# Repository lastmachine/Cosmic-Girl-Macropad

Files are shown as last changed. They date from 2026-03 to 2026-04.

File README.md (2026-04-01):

# Cosmic-Girl-Macropad
A personal cosmic-themed XIAO-RP2040-powered macropad for games, video editing, or anything you'd like to customize. It features 9 MX-style switches, 1 EC11 rotary encoder, and a 128x32 OLED screen.

Having 9 keys makes it perfect for media editing and streaming; those are the main usages I want to give it. Of course, this macropad would work for anything else that allows custom binds. KMK firmware written in Python, is open to modifications 

It is called "Cosmic Girl" because I really like the song of the same name created by the band "Jamiroquai," and also space aesthetics.

Made using KiCad, Fusion 360, and Visual Studio Code. For Hack Club Blueprint.

## Render & Snapshot - Fusion 360
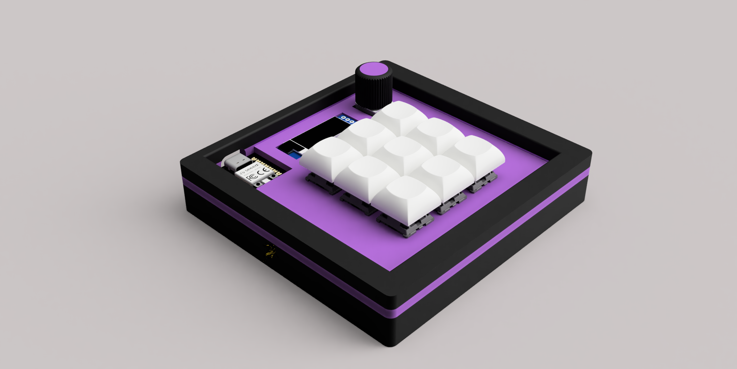
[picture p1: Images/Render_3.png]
Render

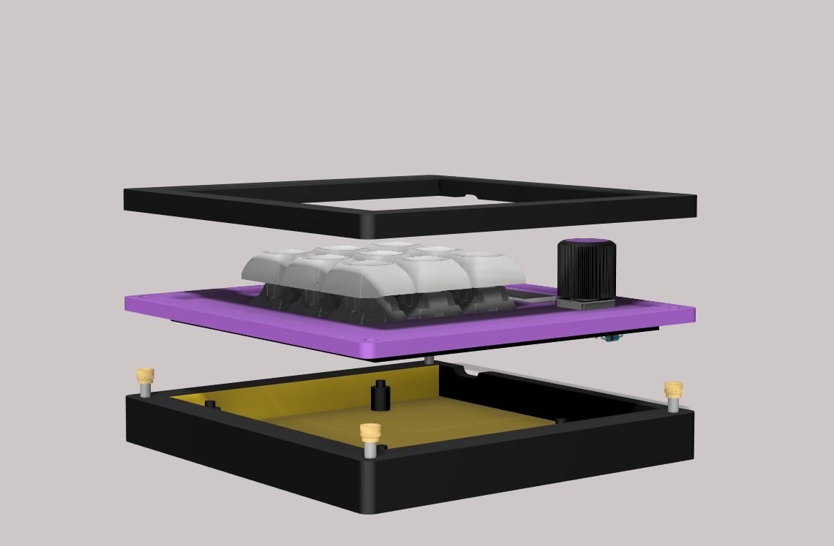
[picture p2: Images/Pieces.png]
Parts

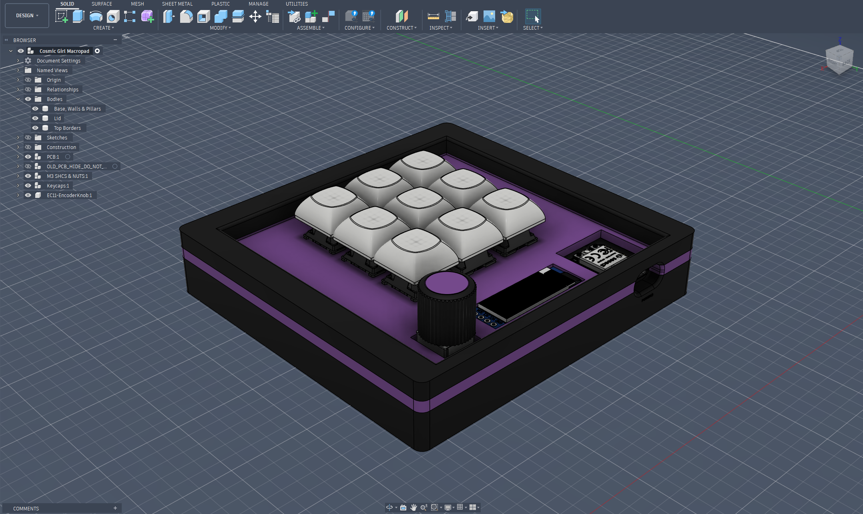
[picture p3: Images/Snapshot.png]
Snapshot

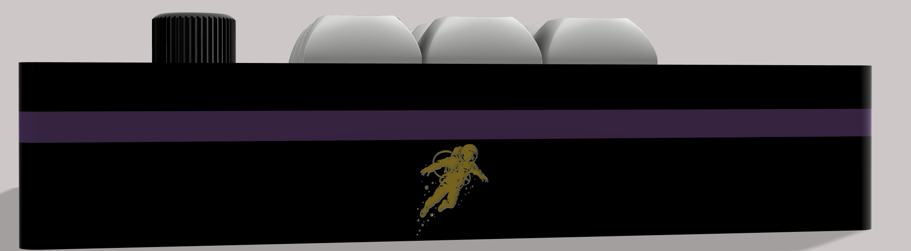
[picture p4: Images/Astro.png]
Astro


---
## PCB & Schematic - KiCad 
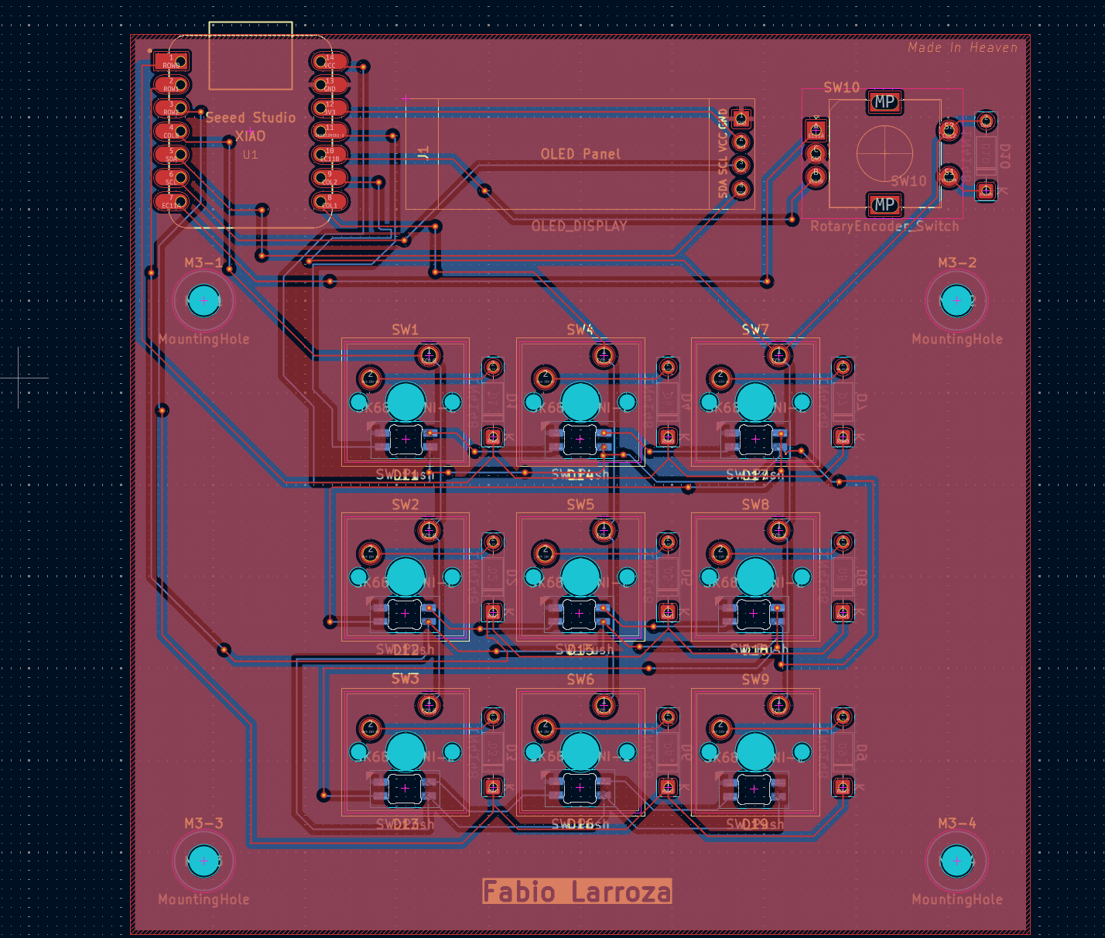
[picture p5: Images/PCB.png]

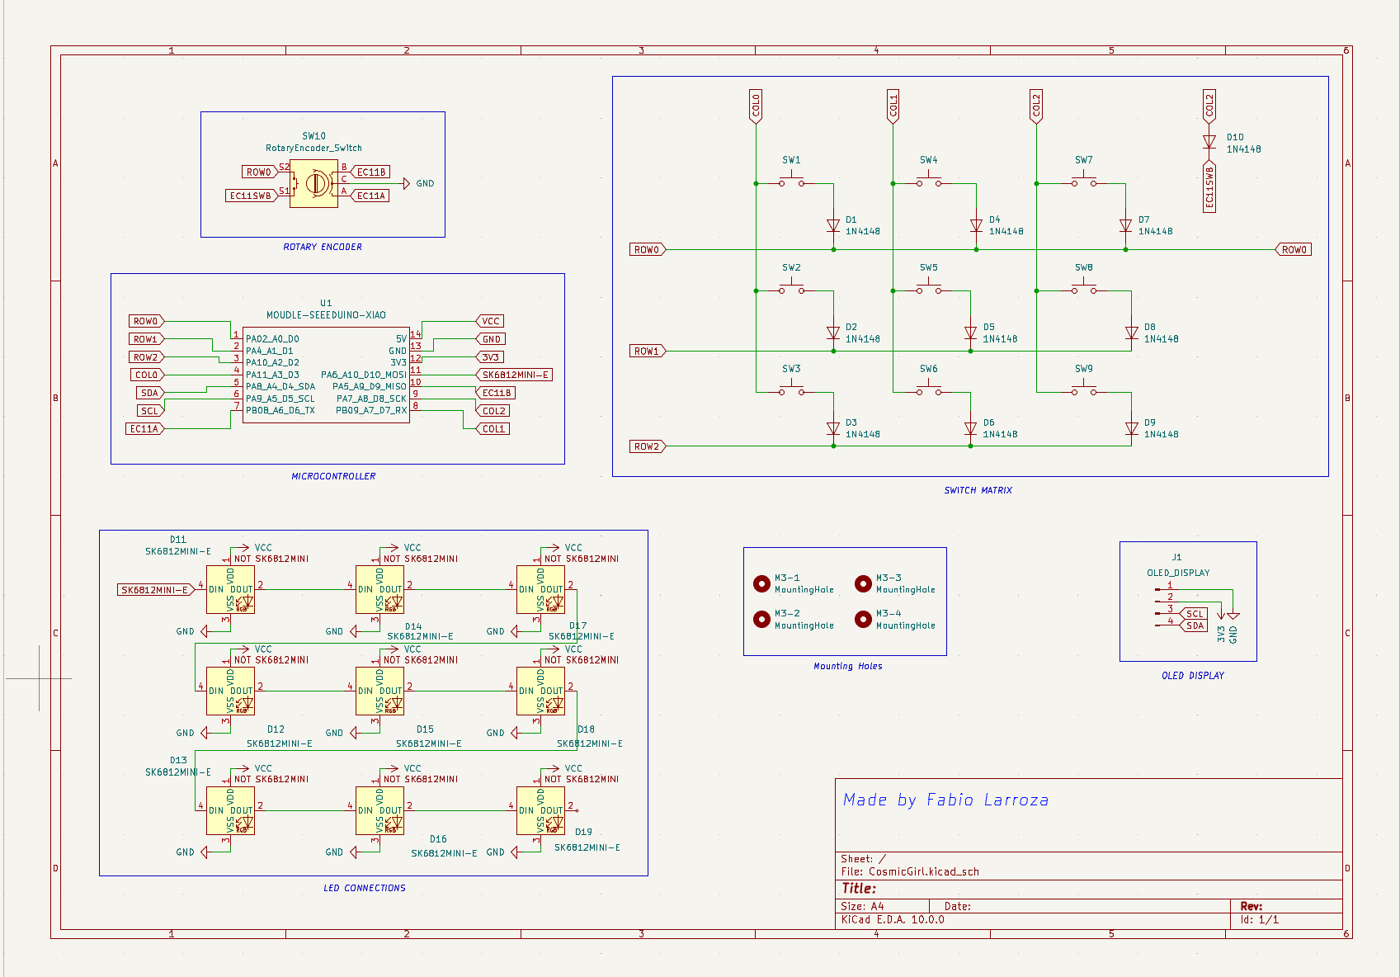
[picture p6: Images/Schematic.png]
Schematic


---
## 3D
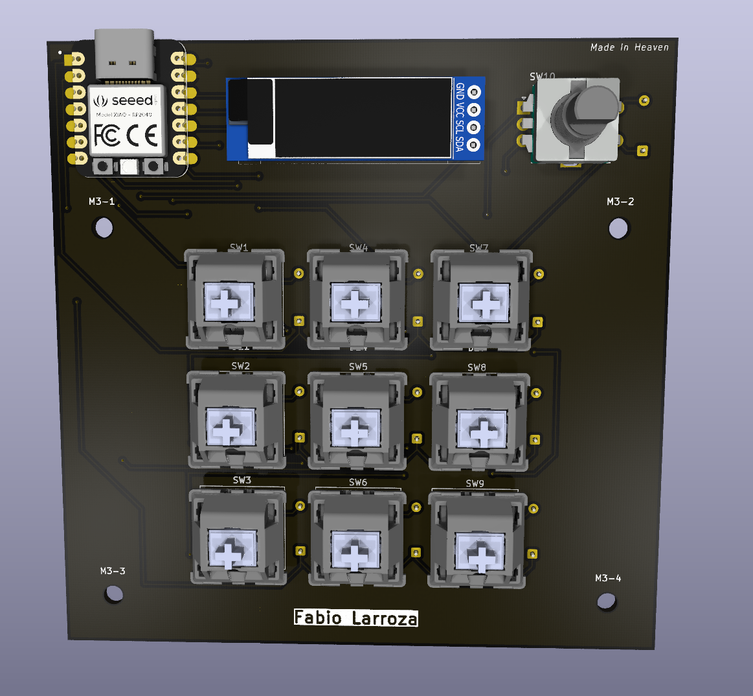
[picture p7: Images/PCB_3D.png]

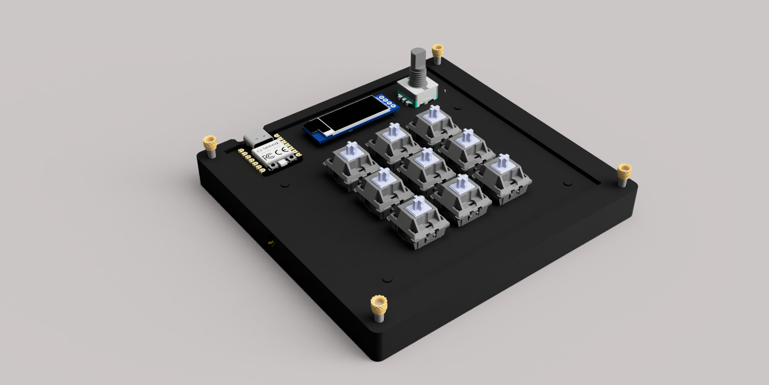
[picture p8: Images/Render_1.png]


---
## Bill of Materials

| Part | Quantity | Details |
|---|---|---|
| Seeed XIAO RP2040 | 1 | Unsoldered |
| 1N4148 Diode | 10 | Through-hole |
| MX-Style Switch | 9 | |
| EC11 Rotary Encoder | 1 | D-Shaft |
| 0.91" OLED Display | 1 | I2C, 128x32 |
| DSA Keycap (white blank) | 9 | |
| SK6812 MINI-E LED | 9 | |
| M3x16mm Screw | 4 | |
| M3x5x4mm Heatset Insert | 4 | |
| Custom PCB | 1 | 2-layer, 98x98mm|

---
## Attribution
Rotary encoder knob model adapted from [EC11 Encoder Knob](https://www.printables.com/model/1000044-ec11-encoder-knob) by Kea Workshop, licensed under GNU GPL v2.0

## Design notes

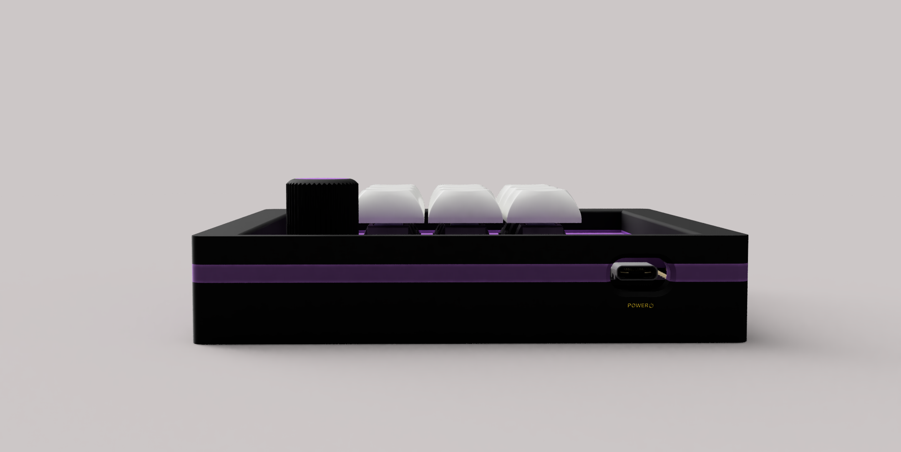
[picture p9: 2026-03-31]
Images/Render_2.png

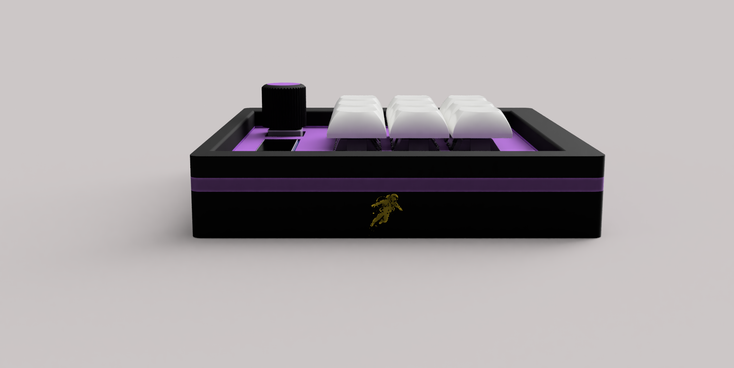
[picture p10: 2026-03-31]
Images/Render_4.png

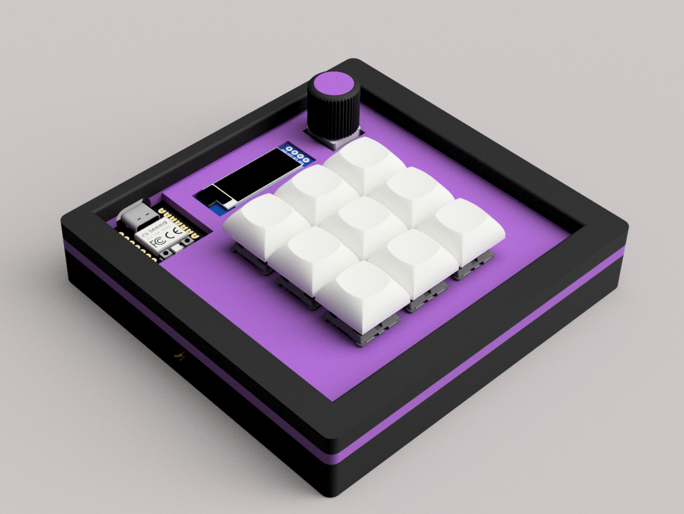
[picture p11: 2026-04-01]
Images/Closeup_model.png

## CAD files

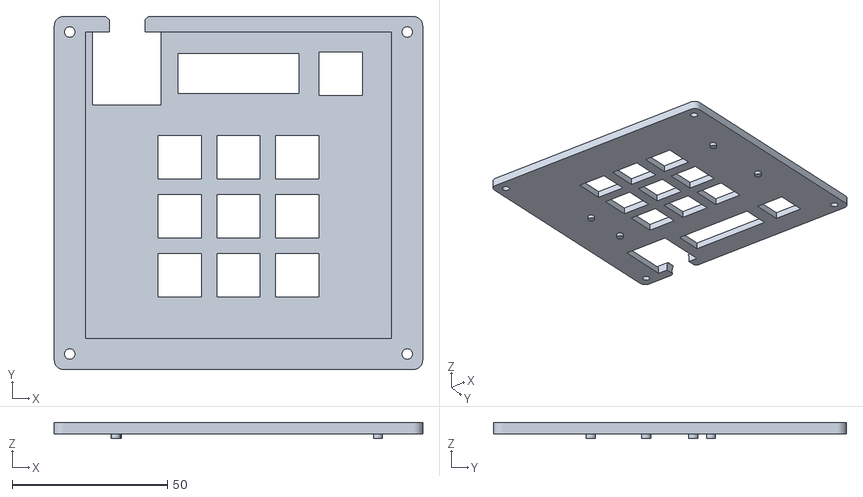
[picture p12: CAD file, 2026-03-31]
Production/Lid.stl
118.8 x 113.8 x 5.30

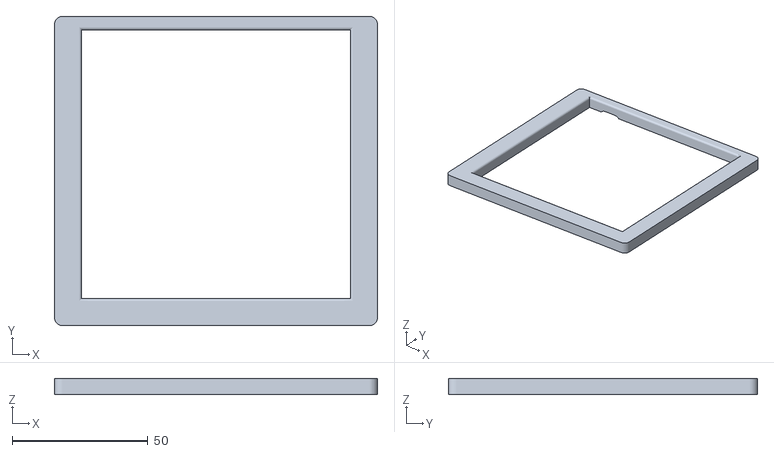
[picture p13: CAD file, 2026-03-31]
Production/Top Borders.stl
118.8 x 113.8 x 6.00

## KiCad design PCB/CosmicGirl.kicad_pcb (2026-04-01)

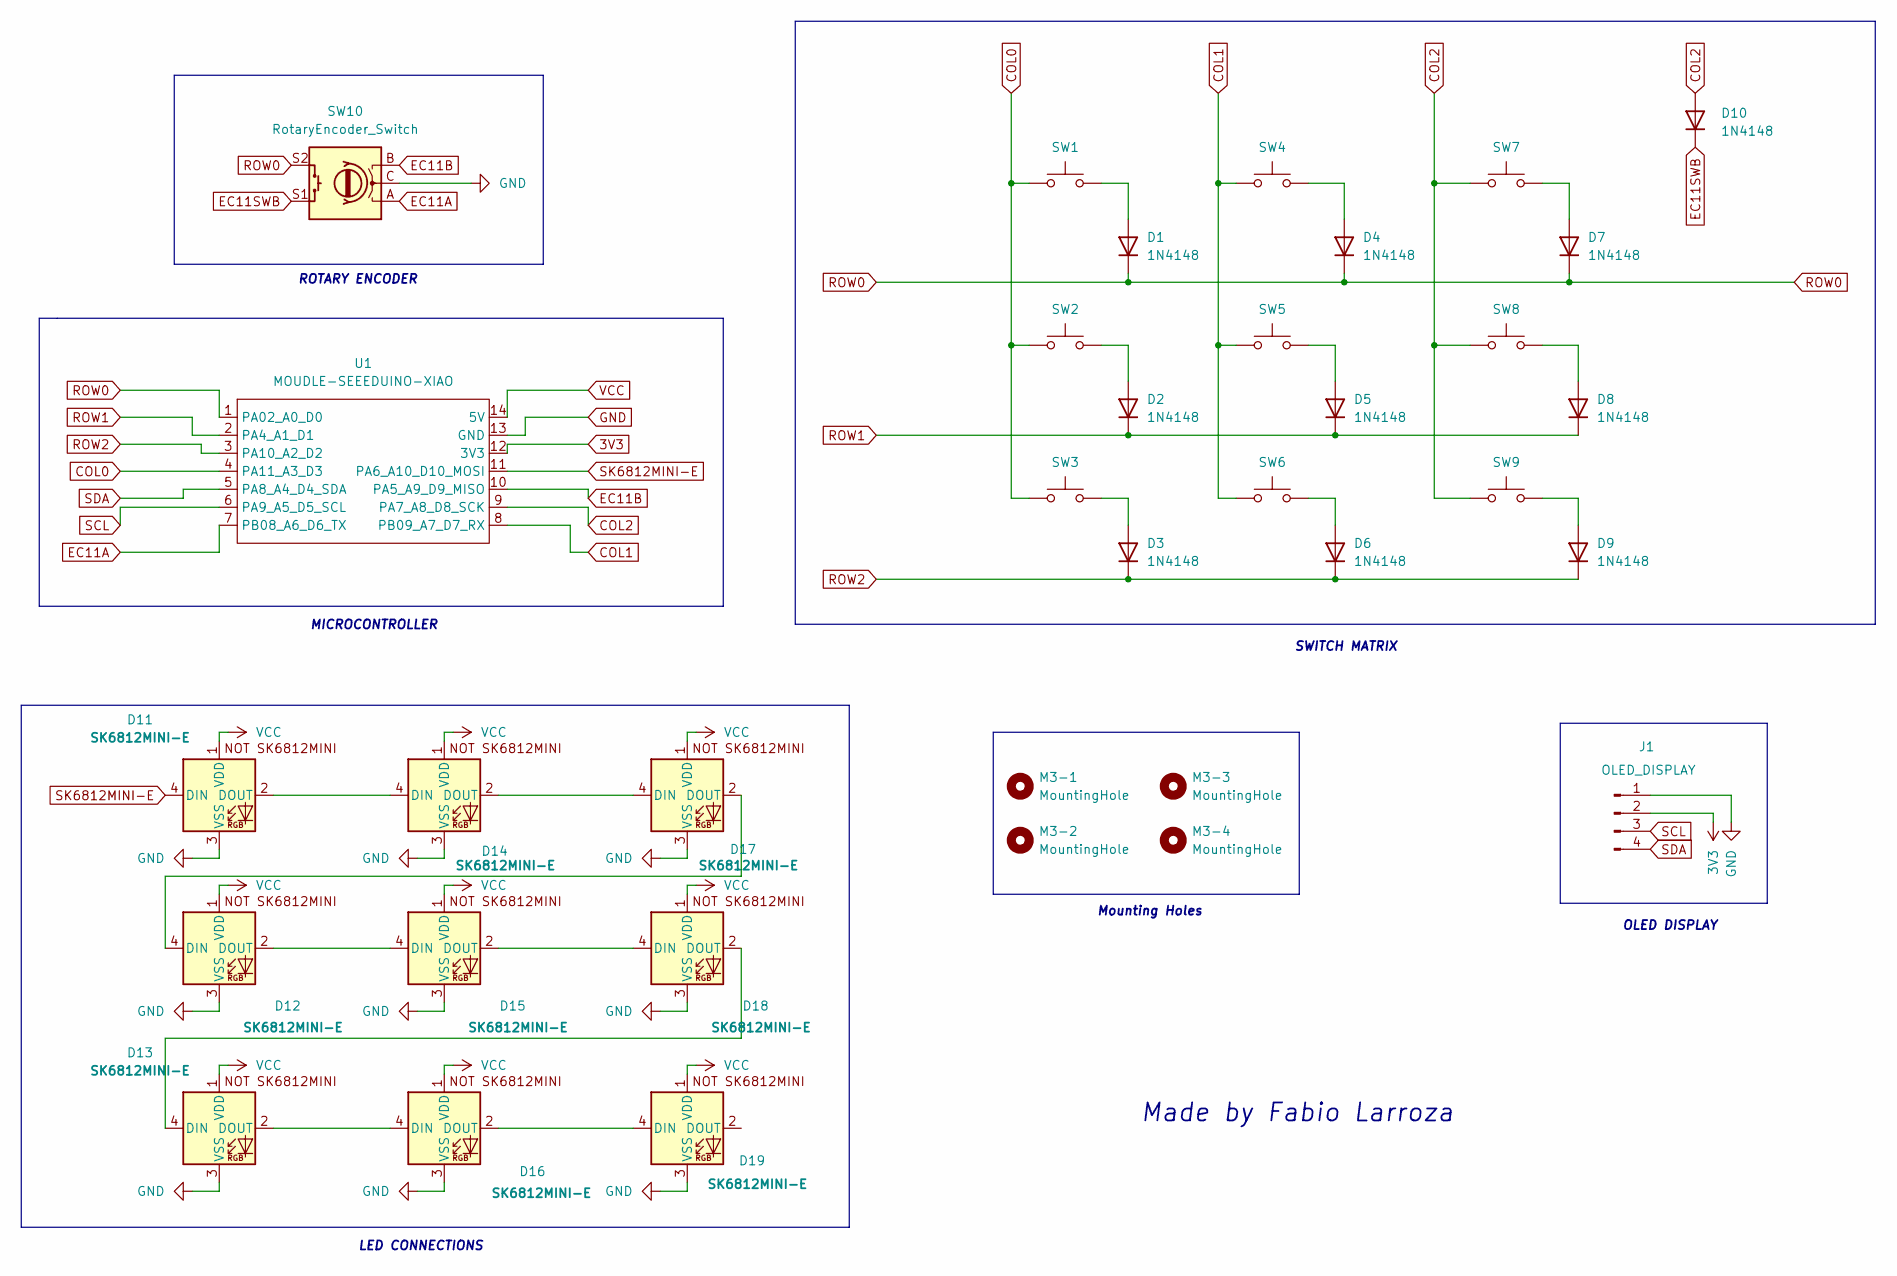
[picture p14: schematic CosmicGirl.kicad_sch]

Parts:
D1, D2, D3, D4, D5, D6, D7, D8, D9, D10: 1N4148; D_DO-35_SOD27_P7.62mm_Horizontal
D11, D12, D13, D14, D15, D16, D17, D18, D19: SK6812MINI-E; SK6812MINI-E_fixed
J1: OLED_DISPLAY; SSD1306-0.91-OLED-4pin-128x32
M3-1, M3-2, M3-3, M3-4: MountingHole; MountingHole_3.2mm_M3
SW1, SW2, SW3, SW4, SW5, SW6, SW7, SW8, SW9: SW_Push; SW_Cherry_MX_1.00u_PCB
SW10: RotaryEncoder_Switch; RotaryEncoder_Alps_EC11E-Switch_Vertical_H20mm
U1: MOUDLE-SEEEDUINO-XIAO; XIAO-Generic-Hybrid-14P-2.54-21X17.8MM

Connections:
3V3: J1.2, U1.12 (3V3)
COL0: SW1.1, SW2.1, SW3.1, U1.4 (PA11_A3_D3)
COL1: SW4.1, SW5.1, SW6.1, U1.8 (PB09_A7_D7_RX)
COL2: D10.2 (A), SW7.1, SW8.1, SW9.1, U1.9 (PA7_A8_D8_SCK)
EC11A: SW10.A, U1.7 (PB08_A6_D6_TX)
EC11B: SW10.B, U1.10 (PA5_A9_D9_MISO)
EC11SWB: D10.1 (K), SW10.S1
GND: D11.3 (VSS), D12.3 (VSS), D13.3 (VSS), D14.3 (VSS), D15.3 (VSS), D16.3 (VSS), D17.3 (VSS), D18.3 (VSS), D19.3 (VSS), J1.1, SW10.C, U1.13 (GND)
unnamed: D1.2 (A), SW1.2
unnamed: D2.2 (A), SW2.2
unnamed: D3.2 (A), SW3.2
unnamed: D4.2 (A), SW4.2
unnamed: D5.2 (A), SW5.2
unnamed: D6.2 (A), SW6.2
unnamed: D7.2 (A), SW7.2
unnamed: D8.2 (A), SW8.2
unnamed: D9.2 (A), SW9.2
unnamed: D11.2 (DOUT), D14.4 (DIN)
unnamed: D12.4 (DIN), D17.2 (DOUT)
unnamed: D12.2 (DOUT), D15.4 (DIN)
unnamed: D13.4 (DIN), D18.2 (DOUT)
unnamed: D13.2 (DOUT), D16.4 (DIN)
unnamed: D14.2 (DOUT), D17.4 (DIN)
unnamed: D15.2 (DOUT), D18.4 (DIN)
unnamed: D16.2 (DOUT), D19.4 (DIN)
ROW0: D1.1 (K), D4.1 (K), D7.1 (K), SW10.S2, U1.1 (PA02_A0_D0)
ROW1: D2.1 (K), D5.1 (K), D8.1 (K), U1.2 (PA4_A1_D1)
ROW2: D3.1 (K), D6.1 (K), D9.1 (K), U1.3 (PA10_A2_D2)
SCL: J1.3, U1.6 (PA9_A5_D5_SCL)
SDA: J1.4, U1.5 (PA8_A4_D4_SDA)
SK6812MINI-E: D11.4 (DIN), U1.11 (PA6_A10_D10_MOSI)
VCC: D11.1 (VDD), D12.1 (VDD), D13.1 (VDD), D14.1 (VDD), D15.1 (VDD), D16.1 (VDD), D17.1 (VDD), D18.1 (VDD), D19.1 (VDD), U1.14 (5V)

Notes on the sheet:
OLED DISPLAY
ROTARY ENCODER
LED CONNECTIONS
MICROCONTROLLER
SWITCH MATRIX
Made by Fabio Larroza
Mounting Holes

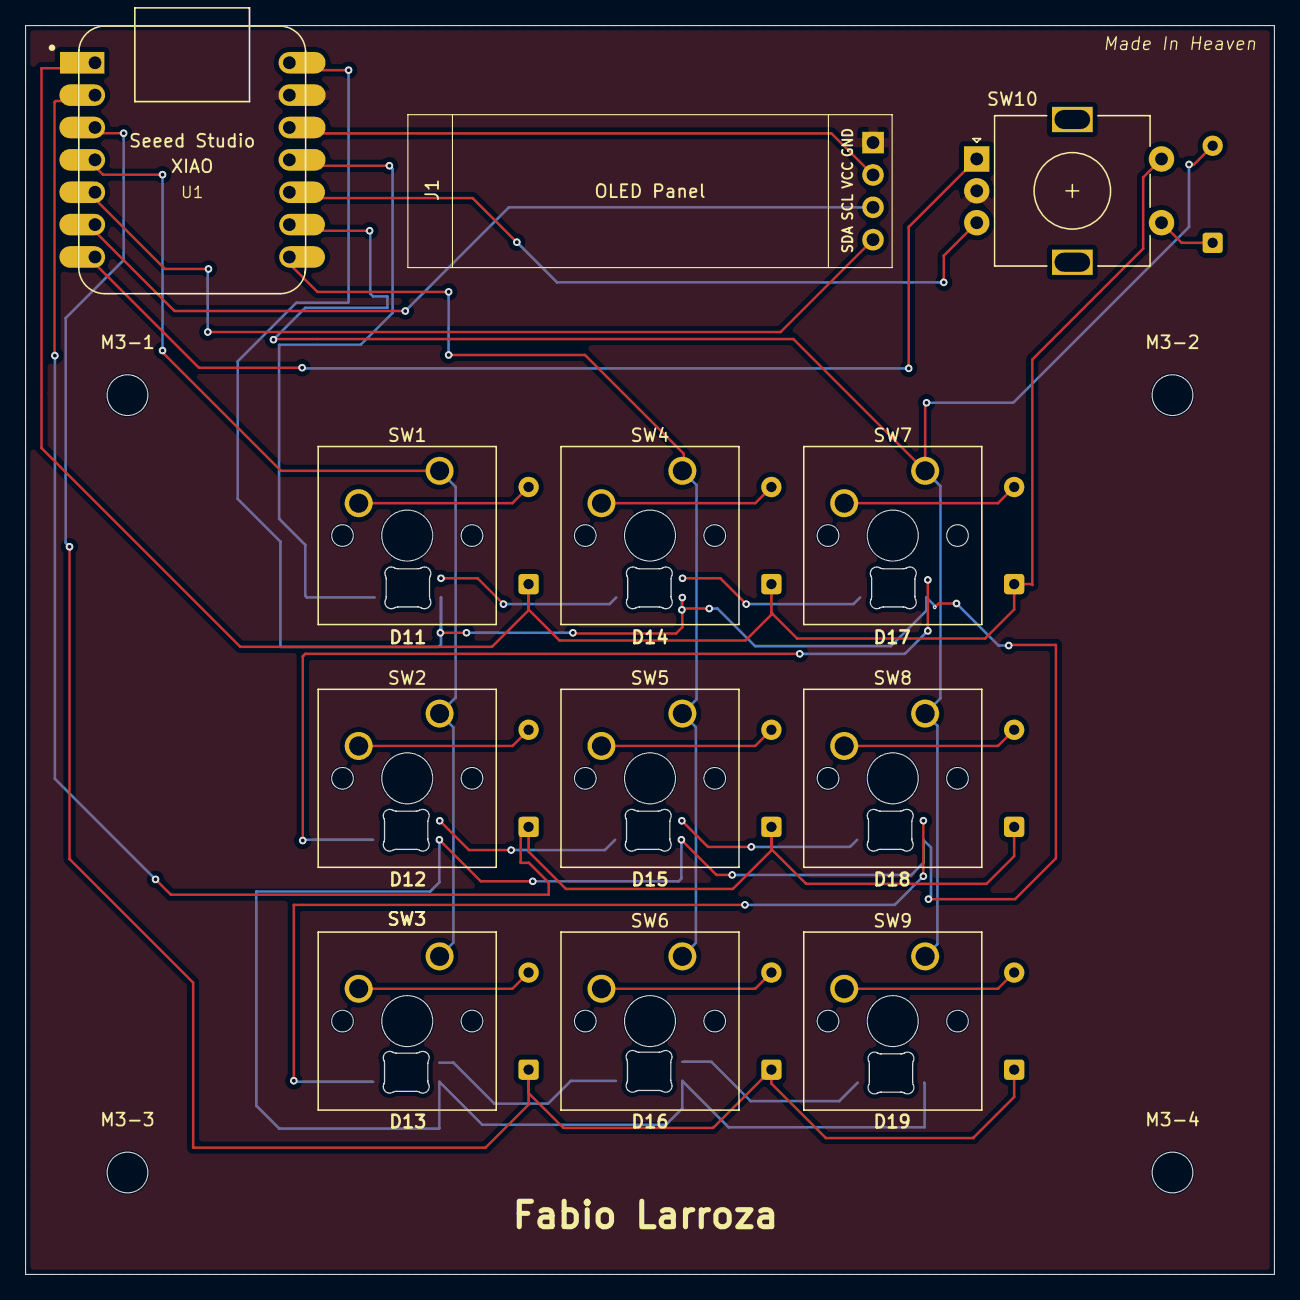
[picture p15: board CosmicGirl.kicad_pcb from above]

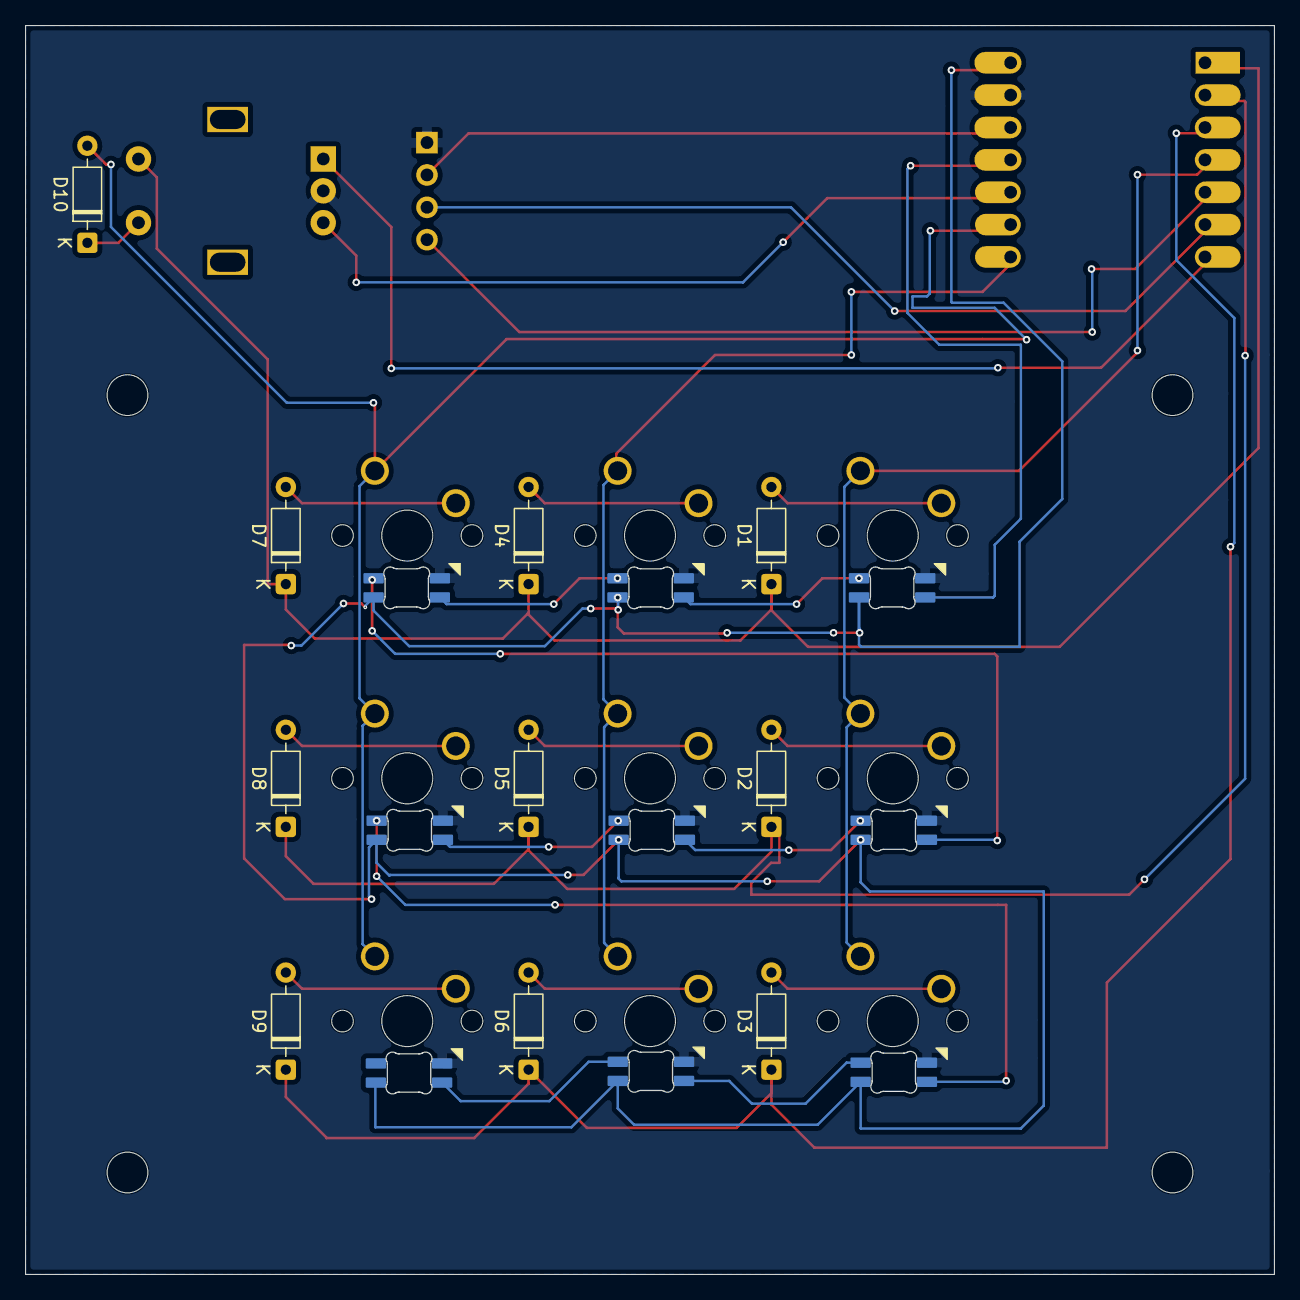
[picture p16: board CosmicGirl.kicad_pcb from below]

Board: 2 copper layers, 98.0 x 98.0 mm, 35 parts (10 on the bottom side), 32 nets.

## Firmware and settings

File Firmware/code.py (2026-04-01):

import board
from kmk.kmk_keyboard import KMKKeyboard
from kmk.scanners import DiodeConfiguration
from kmk.keys import KC
from kmk.modules.encoder import EncoderHandler
from kmk.modules.layers import Layers
from kmk.extensions.media_keys import MediaKeys
from kmk.extensions.RGB import RGB
from kmk.extensions.oled import OLED, OLED_DisplayMode

keyboard = KMKKeyboard()

keyboard.row_pins = (board.D0, board.D1, board.D2)
keyboard.col_pins = (board.D3, board.D7, board.D8)
keyboard.diode_orientation = DiodeConfiguration.COL2ROW

encoder_handler = EncoderHandler()
keyboard.modules.append(encoder_handler)
encoder_handler.pins = ((board.D6, board.D9, None),)
encoder_handler.map = [((KC.VOLU, KC.VOLD),)]

keyboard.extensions.append(MediaKeys())

rgb = RGB(pixel_pin=board.D10, num_pixels=9, val_default=50)
keyboard.extensions.append(rgb)

oled = OLED(
    scl=board.SCL,
    sda=board.SDA,
    width=128,
    height=32,
    flip=False,
    display_mode=OLED_DisplayMode.TXT,
    entries=[
        {"t": "Cosmic Girl", "x": 20, "y": 0},
        {"t": "F13-F20 | Vol", "x": 0, "y": 16},
    ]
)
keyboard.extensions.append(oled)

layers = Layers()
keyboard.modules.append(layers)

keyboard.keymap = [
    [
        KC.F13,  KC.F14,   KC.F15,
        KC.F16,  KC.F17,   KC.F18,
        KC.F19,  KC.F20,   KC.MUTE,
    ],
]

if __name__ == '__main__':
    keyboard.go()

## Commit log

2026-03-31 First upload
    Uploading first project files
    [CosmicGirl.kicad_pcb, CosmicGirl.kicad_sch]
2026-03-31 More uploads
    [Lid.stl, Top Borders.stl]
